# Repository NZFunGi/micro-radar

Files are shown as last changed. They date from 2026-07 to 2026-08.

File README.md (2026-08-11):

<h1 align=center>
  📡 Micro Radar
</h1>
<h6 align=center>
  a tiny open-source flight radar for your desk
</h6>
<p align=center>
  
</p>
<p align=center>
  <a href="#prerequisites">PREREQUISITES</a> - <a href="#assembly">ASSEMBLY</a> - <a href="#usage">USAGE</a> - <a href="#fork-features">FORK FEATURES</a> - <a href="#faq">FAQ</a>
</p>

> This is a fork of [AnthonySturdy/micro-radar](https://github.com/AnthonySturdy/micro-radar) with some extra features added - a real coastline overlay, category-colored aircraft, flight route info, and a [companion desktop app](https://github.com/NZFunGi/micro-radar-companion) for configuring it all without a firmware rebuild. See [Fork Features](#fork-features) below for details. Everything in this README up to that section is the original project - assembly, wiring, and base firmware are unchanged.

## Prerequisites

At the core of this project is the ESP32-C3 module with an integrated 240x240 IPS screen. No soldering required. The module does all the heavy lifting.

I used dark grey PLA filament for the print, but any colour will work just fine. For the lens (optional but recommended), you'll need clear-drying epoxy to secure it (not super glue, which will fog up the lens. Ask me how I know.)

### Tools you'll need

- Small screwdriver (for M2 screws)
- Soldering iron (for setting the threaded inserts)

Set up a clean, organised workspace before you start. You'll be handling small components and epoxy, so a dedicated area helps. Keep a damp cloth nearby for cleaning if needed, and ensure your soldering iron has adequate ventilation.

### Shopping List

Everything you need is below. I've linked products I used and recommend for ease of build, though alternatives exist on Amazon and elsewhere. If you deviate from this hardware, you may need to modify the enclosure and/or code.

- [ ] [1.28" Round GC9A01 240x240 IPS Display Module with ESP32-C3 (no-touch)](https://www.aliexpress.com/item/1005008482665220.html)
- [ ] [USB-C Ribbon Extension Cable (5cm, CMUP-CFPCB-BK)](https://www.aliexpress.com/item/1005005371248824.html)
- [ ] [M2 Heat-set Threaded Inserts (+ soldering iron)](https://www.aliexpress.com/item/1005008493831823.html)
- [ ] [32.5mm Round Mineral Glass Lens (optional, recommended)](https://www.aliexpress.com/item/1005004783554496.html)
- [ ] [Gorilla Epoxy (necessary for fitting lens, useful anyway)](https://www.amazon.co.uk/Gorilla-Glue-25ml-Epoxy/dp/B009NQQJFC)

### Accounts / API

This project uses OpenSky's API for retrieving flight data.

I highly recommend making an account, as it's free, and allows the radar to make many more requests per day (400 -> 4000), which makes the live view much more accurate. However, it isn't necessary if you prefer.

You can sign up [here](https://opensky-network.org), or search "OpenSky".

Further info on what to do with the account is in the usage section.

## Assembly

Once you've got all the parts, assembly typically takes 1-2 hours (excluding print time).

**I strongly recommend reading the [Usage](#usage) section before you start assembly.** It'll help with troubleshooting if anything goes wrong. You might want to test the firmware and your hardware before closing everything up.

### Step 1: 3D Print

FFCBBECA-6165-4138-8C84-16AB375511A2_1_105_c

Print all four STLs from `./hardware/stl/`:

- Main enclosure
- Front plate
- Bezel
- 2 spacers

### Step 2: Heat-set Threaded Inserts

**You'll need:** Soldering iron, M2 threaded inserts

Start with the front plate: insert 2mm M2 threaded inserts into the larger holes using the soldering iron.



Next, the two spacers. These might warp slightly, that's fine. Insert 6mm M2 inserts into each.



Finally, the main enclosure. Insert 5mm M2 inserts.



Et voilà.



### Step 3 (Optional): Fitting the Lens



**You'll need:** Clear-drying epoxy, small applicator (match or cocktail stick works)

This is the fiddliest bit. Keep it neat and you'll avoid frustration:

- Apply epoxy to the front plate, not the lens
- Lower the front plate onto the lens (easier to manage excess epoxy)
- Have a cleaner ready for the edges (I used nail polish remover, your mileage may vary)
- Less is more with epoxy
- Work on a surface that won't bond to epoxy



Let the epoxy cure according to its label before moving on.

### Step 4: Bezel

**You'll need:** 2x5mm M2 screws, 2x10mm M2 screws

Secure the bezel to the front plate using 2x5mm M2 screws through the threaded inserts you added earlier.



Screw 2x10mm M2 screws through the remaining two holes. They should protrude from the back.



Peel the protective film off the screen and position it over the lens. The screws you just inserted will guide the display into place.

Before clamping it down with the spacers, **make sure the antenna is attached to the module**. Press it down firmly onto the flat surface until it clicks. Orientation doesn't matter, but you do need this connection otherwise you won't get any WiFi signal.





Now screw the spacers into those protruding screws to clamp the module in place. I recommend keeping the board plugged in at this point to help with alignment. Don't use much force, too much pressure will stress the screen.

Once you're happy with the alignment, you can add a small amount of epoxy around the module to lock it in place permanently (optional, but recommended if you're happy with the build).

### Step 5: Final Assembly

**You'll need:** USB-C ribbon extension cable, 4x7mm M2 screws, optional rubber feet

Attach the USB-C ribbon cable to the case with the provided nuts and bolts.





If you like, remove the supports from the bottom and insert rubber feet.



Plug in the board, then attach the front plate using 4x7mm M2 screws.



Done!



## Usage

### Flashing the Firmware

You'll need [VS Code](https://code.visualstudio.com/) with the [PlatformIO IDE extension](https://marketplace.visualstudio.com/items?itemName=platformio.platformio-ide) installed. Once installed, restart VS Code, open the repository folder, and dependencies will pull in automatically.

Plug the board in via USB-C, then hit the upload button (→) in the bottom status bar. If the board doesn't reboot with the new firmware automatically, hold the BOOT button on the back and press RESET once, then release BOOT.

The board should auto-detect, but if you hit an upload failure, check that the correct board is selected in the status bar. If it still won't upload, try:

- Disconnect and reconnect the USB cable
- Check that your cable supports data transfer (some USB-C cables are charge-only)
- Try a different USB port on your computer

Read more about PlatformIO [here](https://docs.platformio.org/en/latest/).

### First Boot

On first boot, the radar broadcasts a WiFi hotspot called `MicroRadar-Setup`. Connect to it from your phone or laptop and a configuration page will appear automatically (or go to your browser if it doesn't). Enter your WiFi credentials and hit save. The board will restart and connect to your network.

If the hotspot doesn't appear straight away, give it a moment. If it still hasn't appeared after 30 seconds, exit the WiFi settings on your device and go back in to force a refresh. It'll usually show up then.

### Configuration

Once connected to your network, the radar config is accessible at [http://microradar.local](http://microradar.local) from any device on the same network.

Here you can set:

- **Location** (latitude and longitude): the centre point of your radar
- **Radar radius**: how wide the scan extends (in degrees, 2 degrees is the limit to avoid rate limiting)
- **Display options**: toggle visual elements
- **OpenSky credentials**: your client ID and secret (if you've made an account - again, highly recommend!)



If you've made an OpenSky account (which I highly recommend), you can find your credentials under your account settings at opensky-network.org. With authentication, you get 4000 requests per day instead of 400, making the live view much more accurate. Read more about the API [here](https://opensky-network.org).

This configuration page is accessible anytime the device is connected to WiFi, so you can tweak settings whenever you want.

That's it! Once you've configured everything, you should see a live view of all flights over your location. Enjoy :)



## Fork Features

This fork adds a few things on top of the original project:

### Coastline overlay

The radar background renders real land/sea data instead of a plain black screen, using coastline data from OpenStreetMap. One location's worth of data is baked into the firmware as a fallback (`include/EmbeddedCoastline.h`), but the real way to get accurate coastline for *your* location is the [companion app](#companion-app) below, which fetches and pushes fresh data for wherever you've configured the radar.

<p align="center">
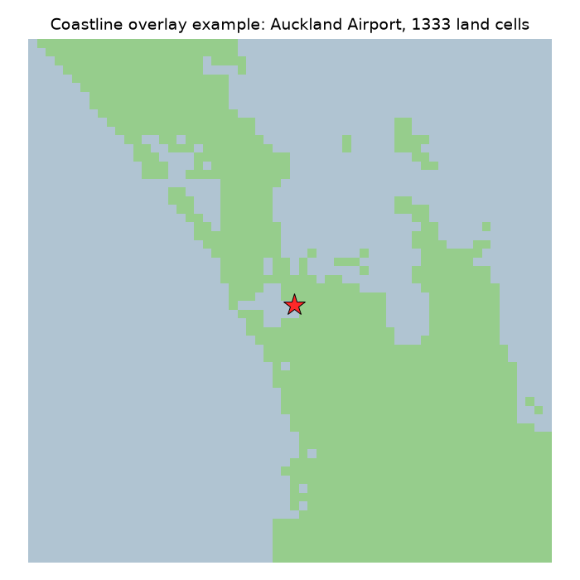
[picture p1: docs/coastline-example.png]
Coastline overlay example
  
</p>

Sea and land colors (along with every other color on screen) are configurable at runtime - see the companion app.

### Category-colored aircraft

Aircraft are colored by their OpenSky emitter category (light, large, heavy, rotorcraft, glider, or unknown) instead of a single fixed color, making it easier to tell traffic types apart at a glance.

### Flight number & route info

Each aircraft label shows its flight number, and - once resolved - its origin and destination airport (`O: <code>` / `D: <code>`). Every callsign is tried against [hexdb.io](https://hexdb.io) first (a free, no-signup-required routes API with a generous rate limit, completely separate from OpenSky's budget), and only falls back to OpenSky's own `/api/routes` for callsigns hexdb.io doesn't have - hexdb.io alone is known to miss roughly half of real routes, but between the two sources coverage is noticeably better than OpenSky alone, especially for regional/domestic traffic that OpenSky's crowdsourced route data tends to under-cover. Results are shown as IATA codes (e.g. `AKL`) regardless of which source resolved them, converting OpenSky's ICAO-only results via an embedded airport code table.

OpenSky lookups are still throttled to share the same daily request budget as position polling, so a flight that only hexdb.io misses can take a little while to resolve; already-seen callsigns are cached for the rest of the session (bounded to the 300 most recently resolved, so the cache can't grow unbounded over a multi-day uptime). The lookup queues are also kept trimmed to whatever's currently on screen, so a busy area can't leave currently-visible aircraft permanently stuck behind a backlog of ones that have already left; and a transient error from either source (rate-limited, momentary outage, etc.) is retried rather than being treated as a confirmed "no route on file".

### Range shown in km

The current radar range is displayed at the top of the screen (e.g. "Range = 100km"), and both the on-device web config page and the companion app show/accept range in km rather than degrees.

### Companion app

A Windows desktop app - [NZFunGi/micro-radar-companion](https://github.com/NZFunGi/micro-radar-companion) - talks to the device over the same USB connection used for flashing, letting you:

- Pick colors live (native color picker or type a hex code) - applies instantly, no restart
- Edit location and range (in km)
- Regenerate the coastline overlay for any location/range by fetching real OpenStreetMap data, classifying land vs sea, and pushing it to the device - no firmware rebuild needed
- Set the OpenSky API Client ID/Secret and the four display toggles (radar sweep, aircraft info, directional aircraft, coastline) - previously only settable via the device's own web config page; saving these restarts the device to apply them, since they're only read once at boot
- Change the device's WiFi network/password over USB - no need to rebuild firmware or join the `MicroRadar-Setup` hotspot to switch networks; the device is always reachable over USB to fix a bad WiFi password even if it can't get online

<p align="center">
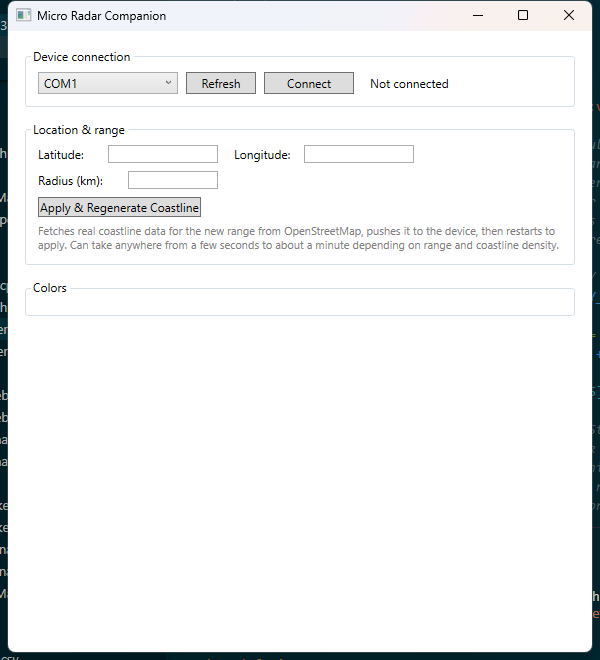
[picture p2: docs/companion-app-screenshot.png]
Companion app screenshot
  
</p>

See that repo's README for setup and usage instructions.

### Bigger NVS partition

The color palette, coastline data, and configuration all live in the device's NVS (flash-backed key/value storage), and a coastline push alone can be several KB - more than fits in the default 20KB NVS partition once you count everything else stored there. This fork uses a custom partition table (`partitions_custom.csv`, 256KB of NVS) instead of the original `huge_app.csv` default. If you're flashing a device that's never run this fork's firmware before, do a full chip erase first so the new partition table takes effect cleanly:

```
pio run --target erase --upload-port <your COM port>
pio run --target upload --upload-port <your COM port>
```

**Note:** a full chip erase wipes WiFi credentials, OpenSky API keys, and all saved settings - you'll go through the `MicroRadar-Setup` WiFi portal again afterward, same as first boot.

## FAQ

> the port is busy or doesn't exist

Restart VS Code *after* plugging in the device. If VS Code was already open, it may default to a stale port from before the device was connected.

If that doesn't work, look for the button with a small "Plug" icon on VS Code's bottom bar (it might say "auto", "cu.usbmodem101", or similar). Click it and select the option that shows your device's name.
<br/><br/>

> the 3D print failed

If you're using a Bambu Lab printer, make sure you're opening the `.3mf` file, since it includes the correct print bed and settings.

Using a different printer? Open an [Issue](../../issues) and I'll try to help where I can.
<br/><br/>

> `ModuleNotFoundError: No module named 'intelhex'` when building

This appears to be a Windows-specific issue. Either of these should fix it:

**Option A:**
1. Open the PlatformIO terminal (PlatformIO sidebar → Miscellaneous → PlatformIO Core CLI)
2. Run `pip install intelhex`
3. Rebuild

**Option B:**
1. Open a new terminal in VS Code (Terminal → New Terminal)
2. Run `python -m pip install intelhex`
3. Rebuild
<br/><br/>

> The coastline overlay looks blank, or shows the wrong shape for my location

The firmware only has one location's coastline data pre-baked in (see [Fork Features](#fork-features)). For anywhere else, use the [companion app](https://github.com/NZFunGi/micro-radar-companion)'s **Apply & Regenerate Coastline** button to fetch and push real data for your actual configured location and range.
<br/><br/>

> I need to change WiFi networks and don't want to go through the `MicroRadar-Setup` portal again

Use the [companion app](https://github.com/NZFunGi/micro-radar-companion)'s **WiFi network** box instead - it sets new credentials over the same USB connection and restarts the device to apply them. If the new credentials turn out to be wrong, the device just won't have WiFi until fixed - reconnect the companion app over USB (which doesn't depend on WiFi at all) and try again.
<br/><br/>

> Route info (`O:` / `D:`) never shows up for some aircraft, just the flight number

Usually expected, not a bug. Every callsign is tried against hexdb.io first (throttled to one lookup every 2 seconds - see [Fork Features](#fork-features)), which should resolve most real routes quickly; misses fall back to OpenSky, which is throttled to share the same daily request budget as position polling (roughly one new lookup every couple of minutes if you're authenticated, longer if not). Every device reboot resets both lookup queues and the cache. Give it a few minutes of uninterrupted uptime; already-resolved callsigns stay cached for the rest of the session. Some aircraft genuinely have no route on file at either source, in which case it'll never resolve.

Double-check the OpenSky Client ID/Secret are actually set (device web config page, or the companion app's **OpenSky API & display options** box) - without them, the anonymous request budget is much smaller and lookups can take on the order of ten-plus minutes each instead of a couple.

If routes seem to *never* resolve at all even after a good few minutes with credentials set, that pointed at a real bug in earlier versions of this fork: any OpenSky response other than a clean success or a confirmed `404` (a `429` rate-limit, a `5xx`, an auth hiccup, etc.) used to get cached as a permanent "no route on file" for that callsign, so one transient error silently and irrecoverably killed that flight's route for the rest of the session. This is fixed as of this version - see `RouteLookupManager::Update()`'s status-code handling - transient errors are now retried instead of cached.

**If you're watching a specific flight you know has a real route (checked on FlightAware/Flightradar24/etc.) and it's just not resolving yet**, this is very likely a backlog, not a bug - and now specifically an *OpenSky fallback* backlog, since hexdb.io's own queue drains fast enough (one every 2 seconds) that it essentially never backs up. Both queues are strict FIFO, so a flight has to wait behind every other distinct callsign queued before it in whichever queue it's in. In a busy area, the OpenSky fallback queue (fed only by hexdb.io misses, so smaller than it used to be, but still throttled to OpenSky's slow shared budget) can still run deep enough that a single flight waits 20+ minutes for its turn - if it leaves your radar's radius before then, it's silently dropped rather than resolved. Watch the serial log for `[INFO] Queued route lookup for <callsign>` followed eventually by either a `->` resolution (tagged `(hexdb.io)` or `(OpenSky)` depending on which source resolved it) or `No route on file` - if you see many `Queued` lines accumulating much faster than resolutions, that confirms it's a backlog. The fix for the OpenSky side is to shift more of the daily OpenSky budget toward route lookups: `OpenSkyBudget::ROUTE_LOOKUP_BUDGET_SHARE` in `include/OpenSkyBudget.h` (default `0.4`, i.e. 40% of the daily quota) controls the split against `/states/all` position polling. Raising it further shortens the OpenSky backlog at the cost of slightly less frequent position updates, which barely matters visually since aircraft already smoothly interpolate between polls rather than jumping.

**If you've checked all of the above and it's still consistently `No route on file` for everything**, including flights you've independently verified are real and scheduled: this is very likely genuine data coverage, not this firmware - both hexdb.io and OpenSky are working as intended, they just don't have that flight on file. Confirmed directly against OpenSky's public API (no device involved): a famous long-haul route (`QFA1`, Qantas' Sydney-Singapore-London service) returns real data, while several genuinely real, currently-scheduled domestic flights (Air New Zealand and Jetstar domestic sectors, tested both with and without the trailing `L` some domestic ATC callsigns carry) all returned a clean `404` from OpenSky - its coverage skews heavily toward well-tracked international long-haul routes rather than domestic/regional traffic. Trying hexdb.io first (see [Fork Features](#fork-features)) closes some of that gap, but hexdb.io is known to miss roughly half of real routes on its own, so between the two some domestic/regional flights will still never resolve - that's a limitation of the underlying free data sources, not something this firmware can fix.

If you're still not seeing routes after checking all of the above, please open an [Issue](../../issues).
<br/><br/>

> I flashed this fork over an existing install and now nothing works / the device won't boot properly

This fork uses a bigger NVS partition than the original (see [Fork Features](#fork-features)), which requires a full chip erase to take effect cleanly on a device that's run different firmware before:

```
pio run --target erase --upload-port <your COM port>
pio run --target upload --upload-port <your COM port>
```

This wipes WiFi credentials and all saved settings, so you'll need to go through the `MicroRadar-Setup` WiFi portal again afterward.

## Notes

> Designed and developed as part of a wedding present for a mate who loves aviation (congratulations to both him and his wife!)

> Inspired by [therealhacksaw](https://www.instagram.com/therealhacksaw/)'s desk radar

> Built with ♥︎ in London

---

> This fork's additions (coastline overlay, category colors, route info, companion app) built with Claude Code

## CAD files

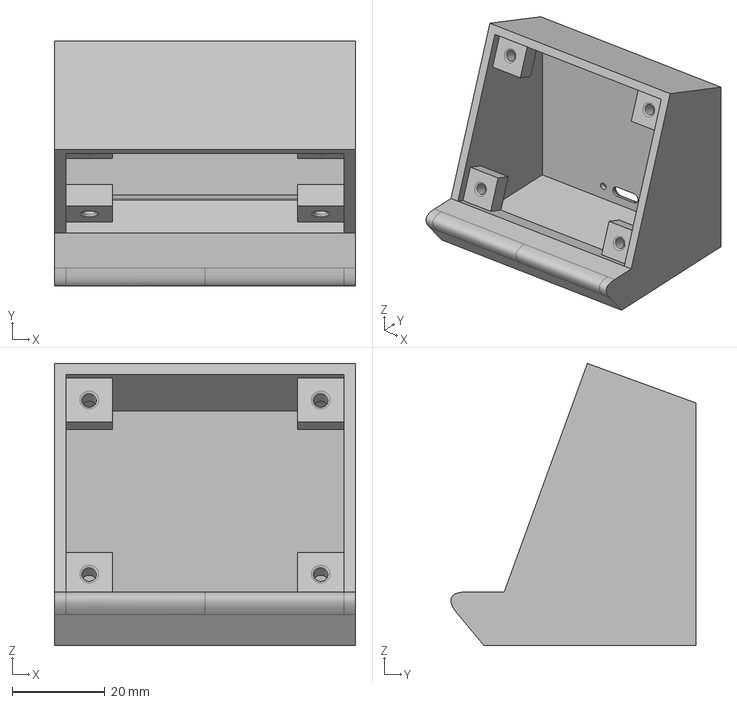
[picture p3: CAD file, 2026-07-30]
hardware/Step/Part Studio 1 - Case and mounting points.step
65.0 x 53.0 x 60.9 mm

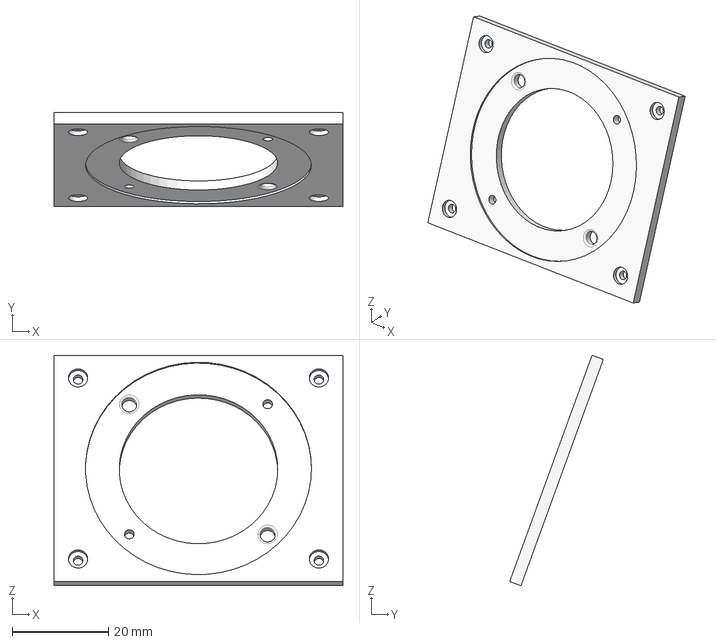
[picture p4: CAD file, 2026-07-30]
hardware/Step/Part Studio 1 - Front Plate.step
60.0 x 19.5 x 47.8 mm

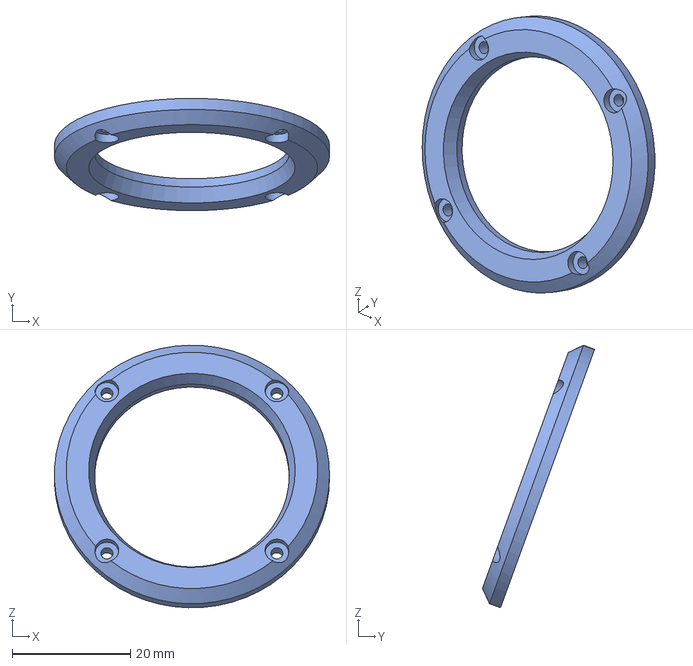
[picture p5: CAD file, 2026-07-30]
hardware/Step/Part Studio 1 - Bezel.step
46.5 x 19.0 x 44.4 mm

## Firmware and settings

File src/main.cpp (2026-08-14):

#include <Arduino.h>
#include <ArduinoJson.h>
#include <WiFiManager.h>

#include "LGFX.h"
#include "WiFiManagerHelpers.h"
#include "ConfigurationWebServer.h"
#include "HttpRequestManager.h"
#include "OpenSkyAuthTokenHandler.h"
#include "RouteLookupManager.h"
#include "AircraftManager.h"
#include "CoastlineManager.h"
#include "CategoryColors.h"
#include "ColorConfig.h"
#include "ColorUtils.h"
#include "DrawHelpers.h"
#include "GeoUnits.h"
#include "SerialCommandManager.h"
#include "models/Aircraft.h"
#include "models/TrackedAircraft.h"

// Optional hard-coded Wi-Fi credentials. Leave both blank to skip pre-baking them and use the setup hotspot instead.
const char* preconfiguredWifiSsid = "";
const char* preconfiguredWifiPassword = "";

constexpr int SCREEN_SIZE = 240;
constexpr int SCREEN_SIZE_DIV_2 = (SCREEN_SIZE / 2);

LGFX tft;
LGFX_Sprite backbuffer(&tft);

WiFiManager wm;
ConfigurationWebServer configServer;
HttpRequestManager http;
OpenSkyAuthTokenHandler authHandler(http);
RouteLookupManager routeManager(configServer, authHandler, http);

AircraftManager aircraftManager(configServer, authHandler, http, tft, routeManager);
CoastlineManager coastlineManager(configServer);
SerialCommandManager serialCommands(coastlineManager);

// Cached at boot rather than read from Preferences/NVS on every single
// render frame (loop() has no frame limiter, so that was tens of flash
// reads + String allocations per second, every second, for the device's
// entire uptime). Safe to cache: every way either of these can actually
// change (SET_TOGGLE/SET_LOCATION over serial, or the web config page's
// POST /save) either explicitly restarts the device itself or is always
// followed by a RESTART as part of the established protocol - see
// SerialCommandManager.h's command list - so a stale in-memory copy
// between boots was never actually possible to begin with.
bool cachedScanlineEnabled = true;
double cachedRadiusDeg = 0.2;

void setup()
{
  // Must be called before Serial.begin() to take effect. The default (256
  // bytes) is fine for ordinary short commands/log lines, but the coastline
  // push protocol sends a whole batch of points (tens of KB) in one burst -
  // any brief stall elsewhere in loop() (an HTTP poll, a render) while that's
  // streaming in silently drops bytes once a 256-byte buffer fills, which is
  // exactly what was wedging SerialCommandManager's coastline receive state.
  Serial.setRxBufferSize(8192);
  Serial.begin(115200);
  // delay(1000); // avoids immediate serial output being cut off - uncomment if needed

  // load the adjustable color palette before anything ever draws with it
  ColorConfig::Initialise();

  // initialise LGFX + screen
  tft.init();
  tft.invertDisplay(true);
  pinMode(3, OUTPUT);
  digitalWrite(3, HIGH);

  backbuffer.setColorDepth(8);
  backbuffer.createSprite(SCREEN_SIZE, SCREEN_SIZE);

  // establish WiFi connection
  tft.fillScreen(lgfx::color888(0, 0, 0));
  tft.setTextColor(lgfx::color888(0, 255, 0));
  tft.drawCentreString("Connecting to WiFi...", SCREEN_SIZE / 2, SCREEN_SIZE / 2);

  WiFiManagerHelpers::ConfigureWiFiManager(wm, tft);

  // Credentials set via the companion app's SET_WIFI (see
  // SerialCommandManager::HandleWifiDataLine) take priority over the
  // hard-coded constants above, since they're the more recently and
  // deliberately configured source - both are just a faster path to a known
  // network than the WiFiManager captive portal below, which remains the
  // fallback either way.
  const String storedWifiSsid = configServer.GetStoredString("wifi-ssid");
  if (!storedWifiSsid.isEmpty()) {
    WiFi.begin(storedWifiSsid.c_str(), configServer.GetStoredString("wifi-password").c_str());
    WiFi.waitForConnectResult();
  } else if (strlen(preconfiguredWifiSsid) > 0) {
    WiFi.begin(preconfiguredWifiSsid, preconfiguredWifiPassword);
    WiFi.waitForConnectResult();
  }

  wm.autoConnect(WiFiManagerHelpers::WiFiManagerName);

  // begin background server for configuration
  configServer.Initialise();

  // initialise aircraft + route lookup managers
  routeManager.Initialise();
  aircraftManager.Initialise();

  // fetch + rasterize coastline for the configured location (one-time, shows its own loading message)
  coastlineManager.Initialise(tft);

  // see the comment on these globals' declaration for why this is safe to
  // read once here rather than every loop() frame
  const String scanlineStored = configServer.GetStoredString("scanline");
  cachedScanlineEnabled = scanlineStored.isEmpty() || scanlineStored == "true";
  cachedRadiusDeg = configServer.GetStoredString("radius").toDouble();
}

void loop()
{
  aircraftManager.Update();
  routeManager.Update();
  serialCommands.Update();

  // draw cycle - clear to the "ocean" tone so the display reads as water by
  // default, even before coastline data has loaded or if it's disabled
  backbuffer.fillScreen(CoastlineManager::SeaColor());

  coastlineManager.Draw(backbuffer);

  if (cachedScanlineEnabled) {
    DrawScanLines(backbuffer,
      SCREEN_SIZE_DIV_2 - 1,
      SCREEN_SIZE_DIV_2 - 1,
      SCREEN_SIZE_DIV_2 - 1 + (std::cos(millis() / 3000.0f) * SCREEN_SIZE_DIV_2),
      SCREEN_SIZE_DIV_2 - 1 + (std::sin(millis() / 3000.0f) * SCREEN_SIZE_DIV_2),
      20, 5,
      CoastlineManager::SeaColor(),
      CategoryColors::RadarColor()
    );
  }

  aircraftManager.Draw(backbuffer);

  // Range label - drawn last so it always sits on top of the coastline,
  // scan lines, and aircraft rather than getting drawn over by any of them.
  // Centred top - close enough to the screen's edge to need the margin
  // check, but a short "90km"-style string comfortably clears the round
  // display's visible circle here (see DrawRadarCircles's OUTER radius).
  const String rangeLabel = String(cachedRadiusDeg * GeoUnits::KM_PER_DEGREE, 0) + "km";
  backbuffer.setTextSize(1);
  backbuffer.setTextColor(ColorConfig::Get(ColorConfig::RANGE_LABEL));
  DrawBoldCentreString(backbuffer, rangeLabel, SCREEN_SIZE_DIV_2, 12);

  backbuffer.pushSprite(0, 0);
}

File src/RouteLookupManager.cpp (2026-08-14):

#include "RouteLookupManager.h"
#include "OpenSkyBudget.h"
#include "EmbeddedAirportCodes.h"

#include <ArduinoJson.h>
#include <algorithm>
#include <cstring>

namespace {
    // hexdb.io's own documented limit is 1000 requests/5min - 400ms would be
    // comfortably under that alone, but a sibling project (touch-radar)
    // confirmed on real hardware that a 400ms-spaced burst of 30+ queued
    // lookups right after boot (a busy traffic period queues one per
    // newly-seen aircraft) was sustained TLS connect/handshake/teardown
    // churn frequent enough to fragment internal RAM and starve an
    // unrelated feature's own TLS handshake ("SSL - Memory allocation
    // failed", every single attempt, across 180s of logging). Widened to
    // give the heap allocator room to coalesce free blocks between
    // requests; costs a slower initial fill of route info after boot, not
    // a functional loss.
    constexpr unsigned long HEXDB_THROTTLE_MS = 2000;

    // Bounds-safe copy into a fixed-size buffer - always null-terminates,
    // silently truncates anything that doesn't fit (only ever expected for
    // malformed/unexpected upstream data, since callsigns and airport codes
    // are documented short - see RouteLookupManager.h).
    void CopyToFixed(char* dest, size_t destSize, const String& src)
    {
        const size_t n = std::min(src.length(), destSize - 1);
        memcpy(dest, src.c_str(), n);
        dest[n] = '\0';
    }
}

void RouteLookupManager::Initialise()
{
    const String token = authHandler.GetValidToken(configServer.GetStoredString("opensky-id"), configServer.GetStoredString("opensky-secret"));
    const bool authenticated = !token.isEmpty();

    openSkyThrottleMs = OpenSkyBudget::MS_PER_DAY / OpenSkyBudget::RouteLookupBudget(authenticated);
    hexdbThrottleMs = HEXDB_THROTTLE_MS;
}

void RouteLookupManager::RequestLookup(const String& trimmedCallsign)
{
    if (trimmedCallsign.isEmpty()) return;
    // Callsigns are documented as up to 8 chars (OpenSky's states/all spec) -
    // cache.callsign only has room for that; silently ignore anything
    // longer rather than risk a malformed/unexpected upstream value
    // overflowing a fixed buffer.
    if (trimmedCallsign.length() > 8) return;
    if (FindCacheEntry(trimmedCallsign) != nullptr) return;
    if (queued.find(trimmedCallsign) != queued.end()) return;
    // Already past its hexdb.io attempt, waiting on the OpenSky fallback -
    // don't re-queue it into the fresh (hexdb.io-first) queue too.
    if (openSkyFallbackQueued.find(trimmedCallsign) != openSkyFallbackQueued.end()) return;

    queue.push_back(trimmedCallsign);
    queued.insert(trimmedCallsign);
    Serial.print("[INFO] Queued route lookup for ");
    Serial.println(trimmedCallsign);
}

void RouteLookupManager::Update()
{
    const unsigned long now = millis();

    // At most one HTTP request per Update() call - prefers draining the
    // hexdb.io queue (cheap, doesn't touch OpenSky's budget) over the
    // OpenSky fallback queue when both have a ready throttle slot.
    if (!queue.empty() && (now - lastHexdbLookup >= hexdbThrottleMs)) {
        lastHexdbLookup = now;
        const String callsign = queue.front();
        queue.pop_front();
        queued.erase(callsign);
        AttemptHexdb(callsign);
        return;
    }

    if (!openSkyFallbackQueue.empty() && (now - lastOpenSkyLookup >= openSkyThrottleMs)) {
        lastOpenSkyLookup = now;
        const String callsign = openSkyFallbackQueue.front();
        openSkyFallbackQueue.pop_front();
        openSkyFallbackQueued.erase(callsign);
        AttemptOpenSky(callsign);
    }
}

void RouteLookupManager::AttemptHexdb(const String& callsign)
{
    // IATA endpoint specifically - hexdb.io returns IATA codes natively
    // here, no conversion needed (unlike the OpenSky fallback below, which
    // only ever has ICAO available).
    HttpResult result = http.Get("https://hexdb.io/callsign-route-iata", { {"callsign", callsign} }, {});

    if (!result.success) {
        Serial.print("[WARN] hexdb.io route lookup failed for ");
        Serial.print(callsign);
        Serial.print(": ");
        Serial.println(result.errorMessage);
        // Transient - don't cache, don't fall back. AircraftManager will
        // re-request this callsign on a later Update() if it's still
        // visible, and RequestLookup() will put it straight back in the
        // hexdb.io queue (it never made it into the OpenSky one).
        return;
    }

    if (result.statusCode == 200) {
        const RouteInfo info = ParseHexdbRouteResponse(result.response);
        if (info.found) {
            CacheRoute(callsign, info);
            LogRouteResult("hexdb.io", callsign, info);
            return;
        }
    }

    // Definitive miss (404, or a 200 with no usable route) - hexdb.io is
    // known to miss roughly half of real routes (see RouteLookupManager.h),
    // so this is the expected common case, not a bug. Fall back to OpenSky
    // rather than caching "not found" outright.
    if (openSkyFallbackQueued.find(callsign) == openSkyFallbackQueued.end()) {
        openSkyFallbackQueue.push_back(callsign);
        openSkyFallbackQueued.insert(callsign);
    }
}
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

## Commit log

2026-07-30 Add coastline overlay, category-colored aircraft, route info, and companion app support
    Extends the original radar with:
    - Real coastline rendering (land/sea colors) built from live OpenStreetMap
    data, with an offline-computed embedded fallback for one location and a
    runtime-pushed NVS-backed dataset for any location
    - Aircraft colored by OpenSky emitter category, with a runtime-adjustable
    color palette (sea/land/radar/each category) stored in NVS
    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
    [Part Studio 1 - Bezel.step, Part Studio 1 - Case and mounting points.step, Part Studio 1 - Front Plate.step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]
2026-08-02 Fix route lookups getting permanently stuck, tune OpenSky budget
    Transient OpenSky errors (429/5xx) were being cached as a confirmed
    "no route on file", permanently killing that flight's O:/D: for the
    rest of the session; they're now retried instead. The lookup queue
    also now drops entries for aircraft no longer in view so a backlog
    can't crowd out currently-visible flights, and the route-lookup share
    of the daily OpenSky budget is raised to shorten that backlog. Serial
    protocol extended so the companion app can configure OpenSky
    credentials and display toggles without the raw web form.
    [RouteLookupManager.cpp, RouteLookupManager.h, SerialCommandManager.cpp]
2026-08-02 Add SET_WIFI serial command to set WiFi credentials over USB
    Lets the companion app change which network the device connects to
    without a firmware rebuild or joining the MicroRadar-Setup hotspot.
    Uses a multi-line exchange (SSID and password on their own lines)
    rather than a space-delimited command, since SSIDs/passwords
    routinely contain spaces - same shape as the existing
    COASTLINE_BEGIN transfer. Credentials set this way take priority at
    boot, ahead of the hard-coded constants, and the device stays
    reachable over USB to fix bad credentials even if WiFi is down.
    [SerialCommandManager.cpp, main.cpp]
2026-08-11 Bound RouteLookupManager's route cache to stop an unbounded leak
    cache never evicted anything, so every distinct callsign ever seen
    stayed in memory for the device's entire uptime - fine for a short
    test session, but exhausts the ESP32's ~300KB heap after a day or two
    in a busy area. Symptoms matched exactly: aircraft silently
    disappearing first (JSON parsing failing for lack of a contiguous
    allocation), then a full lockup once the heap was critically
    fragmented. Now evicts the oldest entry once the cache exceeds 300.
    [RouteLookupManager.cpp, RouteLookupManager.h]
2026-08-11 Pin PlatformIO platform version to avoid a broken toolchain
    An unpinned "platform = espressif32" re-resolved to a newer release
    after a local package cache clear, and that release's bundled
    toolchain-riscv32-esp package couldn't spawn its own assembler (as.exe)
    via its relative-path lookup, breaking every build. Pinned to 7.0.1,
    the version already known to work in this environment.
2026-08-11 Try hexdb.io before OpenSky for route lookups
    hexdb.io is free, needs no signup, and its rate limit is separate
    from OpenSky's shared daily budget, so routing lookups through it
    first noticeably improves route coverage (especially for regional/
    domestic traffic OpenSky's crowdsourced data under-covers) without
    costing anything against position polling. OpenSky remains the
    fallback for hexdb.io's misses (it's known to miss roughly half of
    real routes on its own). Results are normalized to IATA codes via an
    embedded ICAO->IATA table so display is consistent regardless of
    which source resolved a route. Ported from a sibling project
    (touch-radar) that validated this approach - including the 2s
    h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
    [RouteLookupManager.cpp, RouteLookupManager.h]
2026-08-11 Set upload/monitor port to COM5
    Was a leftover macOS path (/dev/cu.usbmodem1101) that never matched
    on Windows, causing uploads to fall back to a stale cached COM4 that
    didn't match the device's actual port.
2026-08-11 Fix range label going off the round screen, match route format
    The bottom-left placement from the last commit put it near a corner
    of the square framebuffer, which is physically outside the round
    display's visible circle - repositioned to stay inside it with
    margin. Also switched O:/D: to a single "AKL - MEL" line, matching
    touch-radar's format, instead of two separate lines.
    [main.cpp]
2026-08-11 Simplify range label to just the number, move back to top-centre
    Drops the "Range = " prefix (just "90km" now) and moves back to
    centre-top - a short string like this comfortably clears the round
    display's edge there.
    [main.cpp]
2026-08-14 Rewrite route cache as a fixed-size array to eliminate heap churn
    The bounded std::map<String, RouteInfo> cache (300 entries, oldest
    evicted first) only capped the cache's *size*, not its ongoing
    malloc/free *churn*: every eviction+insert cycle still freed and
    re-allocated an rb-tree node plus several String heap buffers, and
    that churn, sustained continuously as new callsigns are seen day
    after day, was enough on its own to fragment the heap - reproducing
    the exact "loses aircraft, then locks up after a day or two" symptom
    the size cap was meant to fix. Callsigns (max 8 chars) and airport
    codes (IATA/ICAO, max 4 chars) are naturally short and fixed-length,
    so the whole cache is now a compil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
    [RouteLookupManager.cpp, RouteLookupManager.h]
2026-08-14 Fix ConfigurationWebServer's shared Preferences race condition
    ConfigurationWebServer held one Preferences member used by both its
    AsyncWebServer request handlers (which run on their own FreeRTOS
    task) and GetStoredString() (called constantly from the main loop()
    task) - Preferences has no internal locking, so begin()/end() calls
    from those two tasks could race: one task's begin() silently failing
    and reading through the other's handle (values coming back as
    defaults), or - if both pass the "already started" check before
    either sets it - one handle getting orphaned entirely, permanently
    leaking an NVS handle. Switched to local Preferences instances per
    call, the same pattern SerialCommandMan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
    [ConfigurationWebServer.h]
2026-08-14 Cache radius/scanline at boot instead of reading every render frame
    loop() has no frame limiter, so these were a full Preferences
    begin()/nvs_get_str()/end() round trip plus a fresh String allocation
    tens of times per second, for the device's entire uptime - needless
    flash wear and heap churn, and (with ConfigurationWebServer's shared
    Preferences handle prior to the previous commit) more race windows.
    Safe to cache: every way either value can actually change already
    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
